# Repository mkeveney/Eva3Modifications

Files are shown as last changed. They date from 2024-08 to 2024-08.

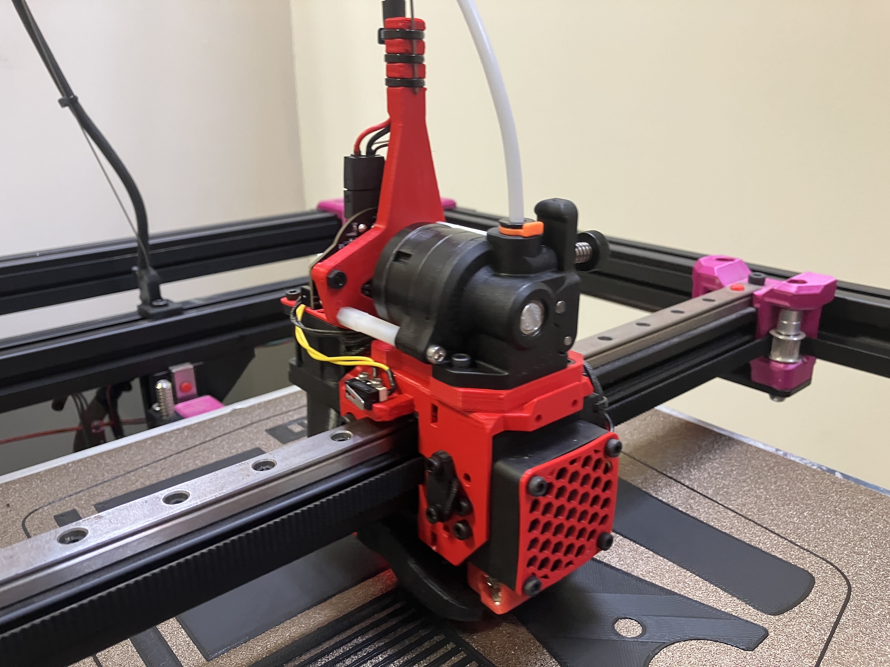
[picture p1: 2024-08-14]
evamods_overall.jpg

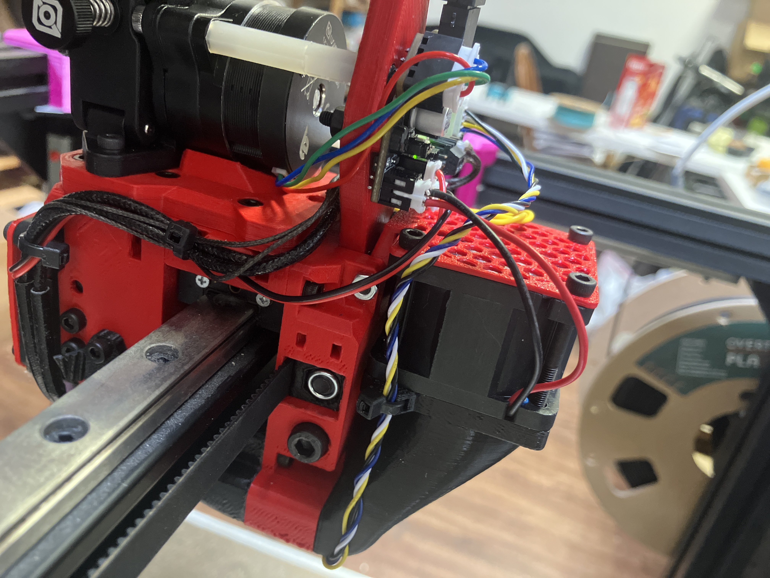
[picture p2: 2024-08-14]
evamods_alternate_4028_fan_rightside.jpg

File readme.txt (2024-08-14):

8/14/2024

I just finished upgrading my RatRig, and have made a few EVA 3 modifications.
It was designed in the following Onshape document, which was copied from the EVA
page.  I've also copied the mesh files to Github, Thingiverse, and Printables.

https://cad.onshape.com/documents/b351c67621eaae69eba7c628/w/d4ddc1c1f22996a018bcad89/e/780d6d940259a333f0b77ea6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

Eva project home page: https://main.eva-3d.page/

The contributions are:

    Alternate Tri-horn fan duct with mount for Beacon scanner.

        My beacon is a D type, and has been assembled in 'low profile' fashion
        with _NO_ connector.  I soldered the wires directly to the circuit board
        to save space.  When I got my Beacon (about a year ago) I contacted
        Beacon support to request a disassembled board.  They suggested instead
        that I let them assemble it for me in this low-profile configuration,
        but without the connector.  This enabled them to complete a testing or
        calibration step or something.  I'm not sure what their current practice
        is so contact them and ask.  I'm also not sure this will fit the new H
        style Beacon, but I suspect the mount holes are the same.

        The mounting cavities in the shroud are sized for M2.5 nuts (5mm across
        flats).  I found that flat-head M2.5 screws still fit and have a very
        low-profile that should minimize chances of hitting the bed, ...though
        this was probably overkill.

        I had to slightly change the path of the central duct to make room for
        the Beacon.  I think the air flow should still be very similar.

    Mount for Nitehawk 36 toolboard, compatible with Orbiter 2 mount.

        I believe this will also fit the BTT EBB36 toolboard.  It has two holes
        which align with the Orbiter stepper motor screws.  I replaced these
        screws with slightly longer 20mm screws, and added nylon stand-offs (see
        the photos).  I had to screw two standoffs together to make the 30mm
        distance.  The 'pillar' that the umbilical mounts to is deliberately
        offset to allow the pigtail to curve a bit for some strain relief.  At
        least that was the idea.

    Alternate mount for 4028 fan, including protective inlet grille.

        This is necessary to provide clearance for the NiteHawk 36 mount wires.
        On my machine, it cleared the rear Z leadscrew without modification, but
        this may depend on how you've adjusted your Y endstop.

        There's also a Zip-tie mount on one side, which I used to secure the
        Beacon wires.

    Modified "Top Endstop" piece to accomodate a bare endstop switch.

        I went this route because I already had a bag of these switches.  If
        you're going to make custom-length wires anyway, I think these are just
        as easy.

    Minimalist grille for front fan.

        I re-used this from some other project.  It's not in the Onshape
        document.

Released under CC 4.0 share-alike license.
    https://creativecommons.org/licenses/by-nc-sa/4.0/

My thanks to all Ratrig and Eva contributors!

-Matt Keveney
keveney.com

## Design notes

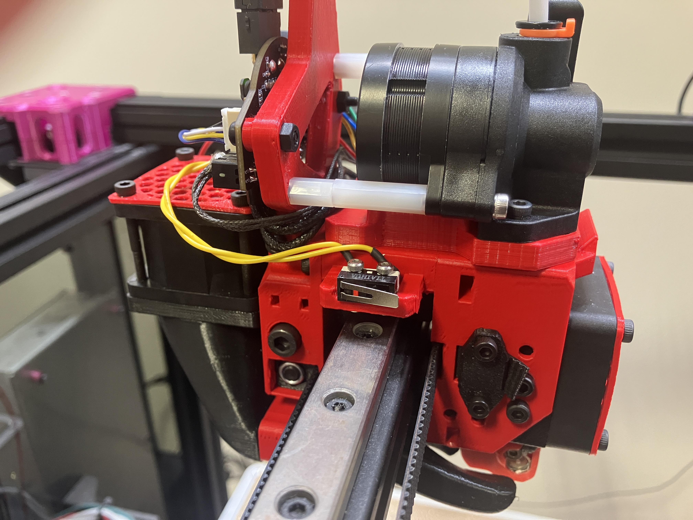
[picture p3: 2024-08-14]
evamods_leftside.jpg

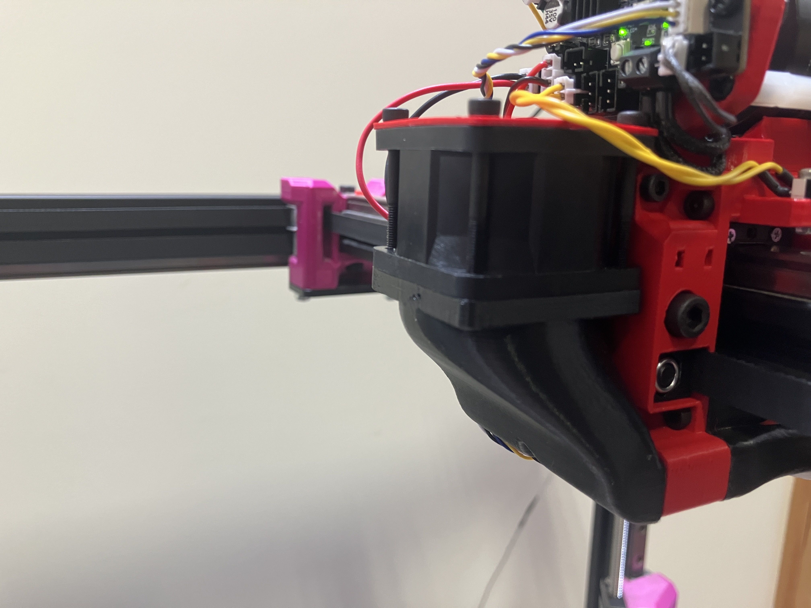
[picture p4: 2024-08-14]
evamods_alternate_4028_fan.jpg

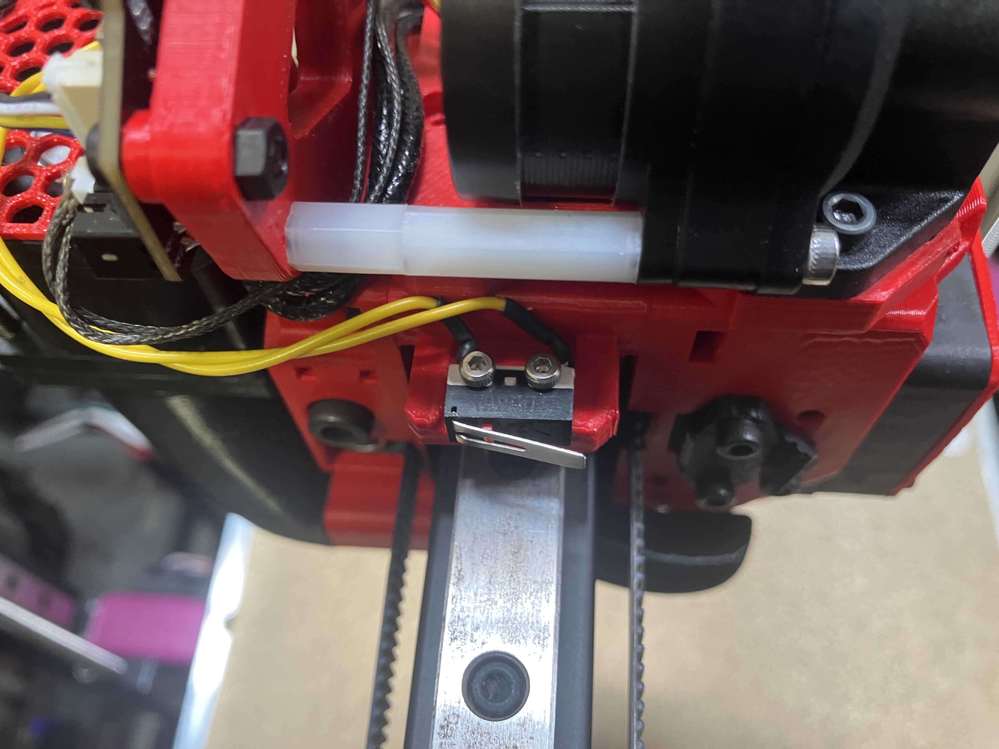
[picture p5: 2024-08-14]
evamods_bareswitch.jpg

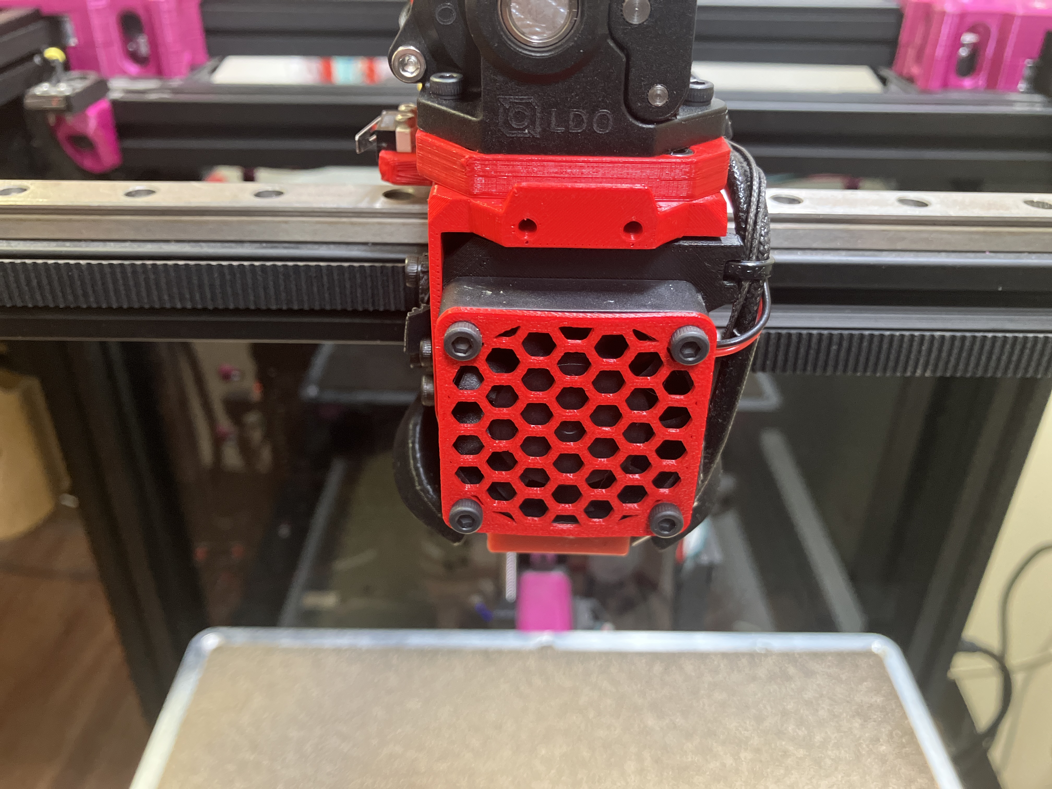
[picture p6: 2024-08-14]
evamods_minimalist_front_grille.jpg

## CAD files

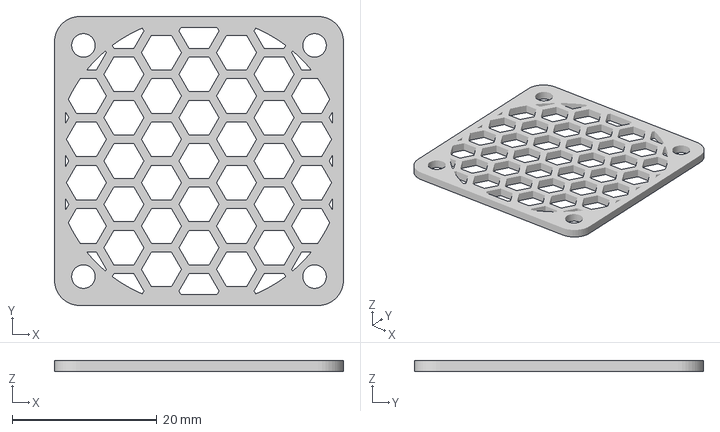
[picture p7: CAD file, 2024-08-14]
front_40mm_fan_grille.3mf
40.0 x 40.0 x 1.50 mm

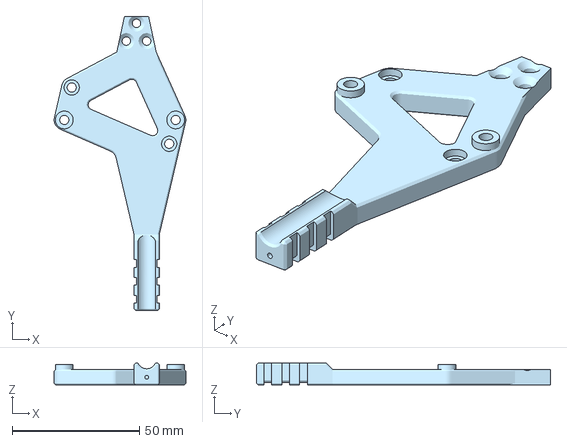
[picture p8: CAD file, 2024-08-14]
Nitehawk_mount_orbiter2.3mf
51.8 x 115.7 x 8.50 mm

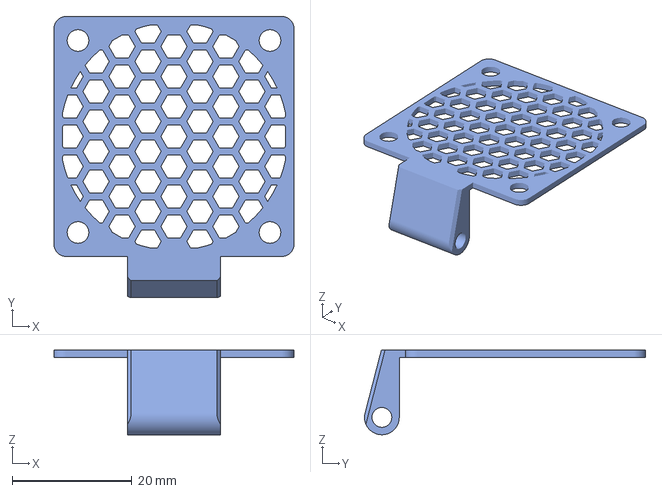
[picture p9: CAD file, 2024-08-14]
40mmInletAlt_fangrille.3mf
40.0 x 46.8 x 14.1 mm

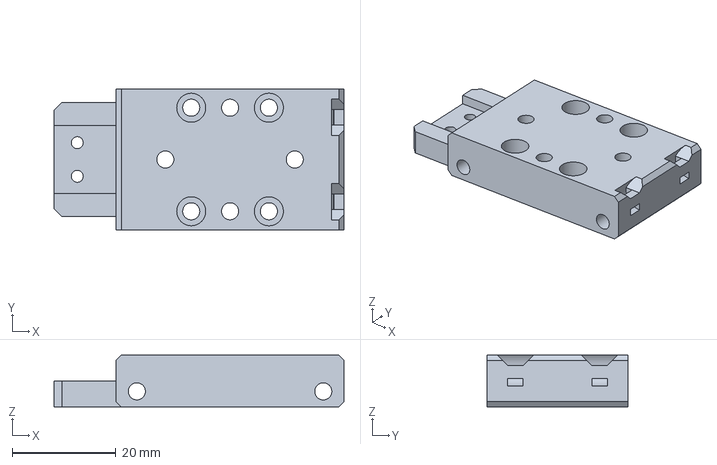
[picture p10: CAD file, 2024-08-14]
top_endstop_bareswitch.3mf
56.0 x 27.3 x 10.0 mm

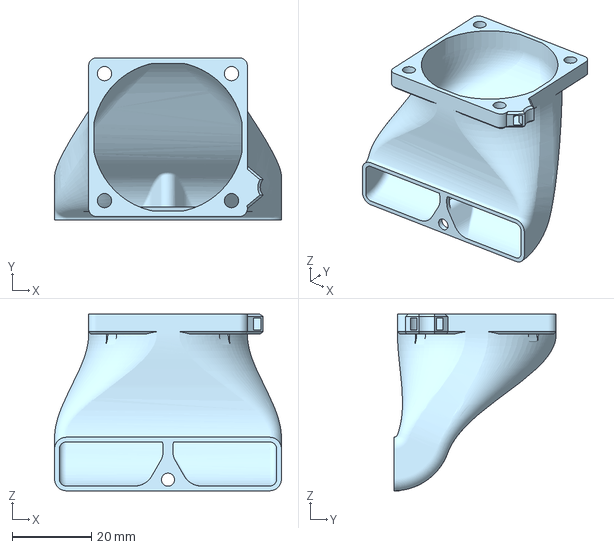
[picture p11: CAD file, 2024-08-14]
40mmInletAlt.3mf
57.2 x 40.9 x 44.5 mm

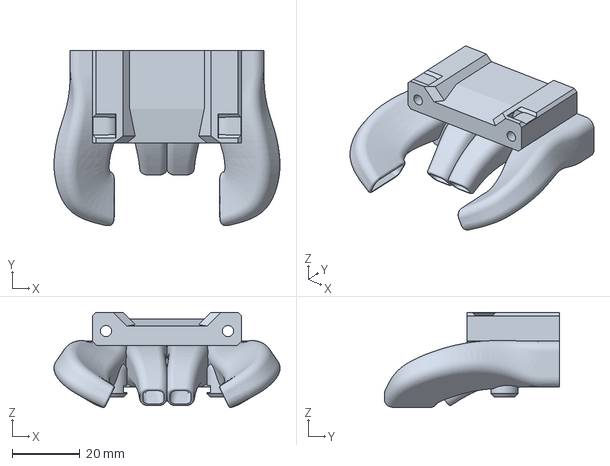
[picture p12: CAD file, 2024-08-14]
bottom_trihorns_mosquito_beacon.3mf
66.7 x 51.7 x 28.1 mm
